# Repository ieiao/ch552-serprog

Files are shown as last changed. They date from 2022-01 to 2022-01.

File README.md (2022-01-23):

# ch552-serprog

# 简介

使用ch552设计的兼容[flashrom](https://flashrom.org) serprog协议的SPI nor flash烧录器，支持3.3V和1.8V电压。

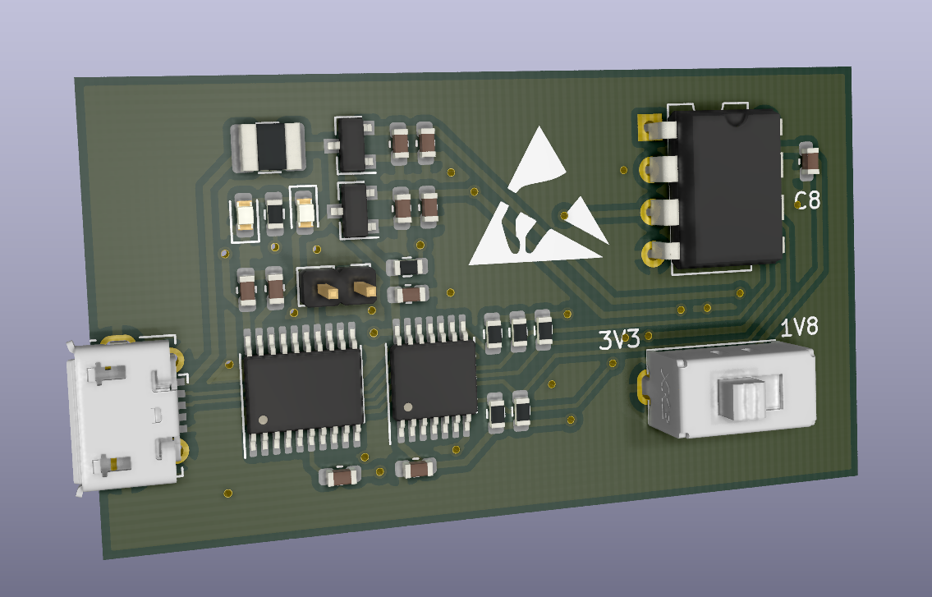
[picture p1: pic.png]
效果图


# 固件

本仓库仅包含原理图及PCB文件，程序在[这个仓库](https://github.com/ieiao/ch554_sdcc)的`serprog`分支`examples/serprog`目录下。

# 使用方法

```shell
$ # 读flash
$ flashrom -p serprog:dev=/dev/ttyACM0:4000000 -r /tmp/read.bin
$ # 擦除flash
$ flashrom -p serprog:dev=/dev/ttyACM0:4000000 -E
$ # 写flash
$ flashrom -p serprog:dev=/dev/ttyACM0:4000000 -w /tmp/read.bin
```

受ch552性能以及程序实现影响，flash读写速度未能达到上限，以下是使用SST25VF032B 32Mbit(4Mbyte) flash测出的读写平均耗时

| 操作 | 耗时 |
| :--: | :--: |
| 全片读 | 10s |
| 全片擦除 | 30s |
| 全片读+写+校验 | 32s |

# 备注

* 原理图中的led灯需要二选一焊接，不可全部焊接
* 如果使用TXS0104，flash测上拉电阻可以不焊接

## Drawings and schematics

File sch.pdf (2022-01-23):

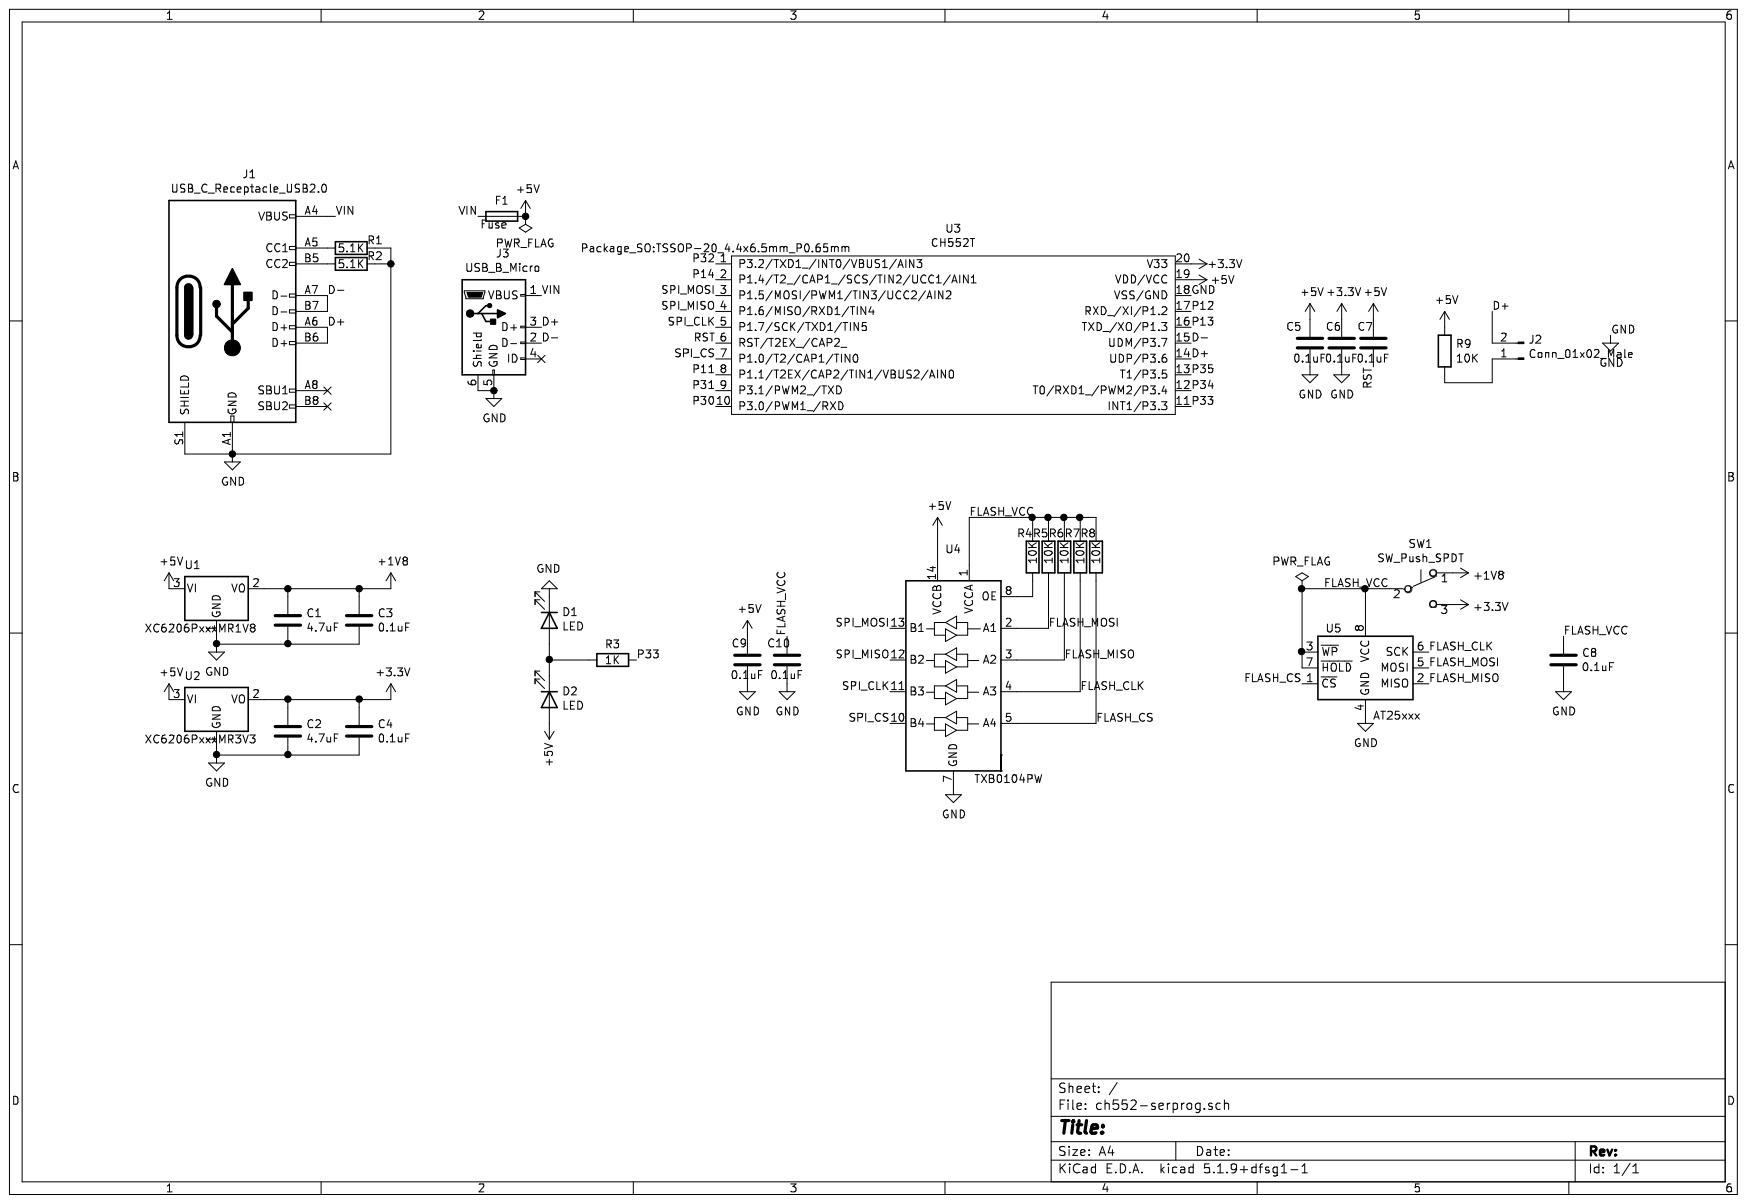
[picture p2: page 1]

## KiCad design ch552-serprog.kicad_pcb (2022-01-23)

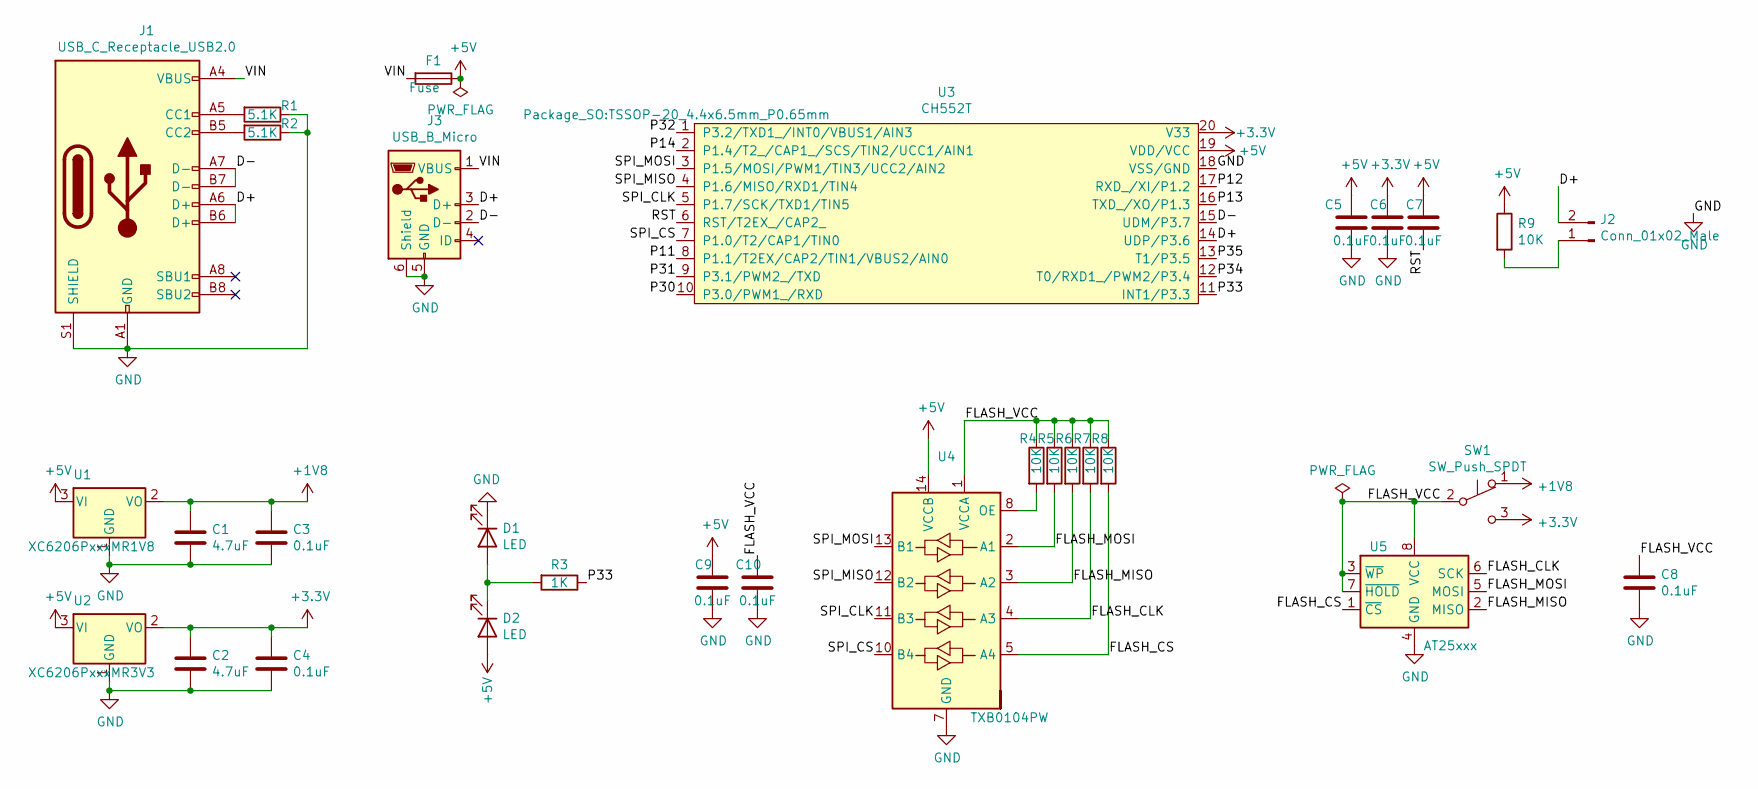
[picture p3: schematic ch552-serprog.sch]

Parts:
C1, C2: 4.7uF; C_0603_1608Metric
C3, C4, C5, C6, C7, C8, C9, C10: 0.1uF; C_0603_1608Metric
D1, D2: LED; LED_0603_1608Metric
F1: Fuse; Fuse_1210_3225Metric
J1: USB_C_Receptacle_USB2.0; USB_C_Receptacle_Palconn_UTC16-G
J2: Conn_01x02_Male; PinHeader_1x02_P2.00mm_Vertical
J3: USB_B_Micro; USB_Micro-B_Molex-105017-0001
R1, R2: 5.1K; R_0603_1608Metric
R3: 1K; R_0603_1608Metric
R4, R5, R6, R7, R8, R9: 10K; R_0603_1608Metric
SW1: SW_Push_SPDT; SW-DIP-3
U1: XC6206PxxxMR1V8; SOT-23
U2: XC6206PxxxMR3V3; SOT-23
U3: CH552T; TSSOP-20_4.4x6.5mm_P0.65mm
U4: TXB0104PW; TSSOP-14_4.4x5mm_P0.65mm
U5: AT25xxx; DIP-8_W7.62mm

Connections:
+1V8: C1.1, C3.1, SW1.1 (A), U1.2 (VO)
+3V3: C2.1, C4.1, C6.2, SW1.3 (C), U2.2 (VO), U3.20 (V33)
+5V: C5.2, C7.2, C9.2, D2.2 (A), F1.1, R9.1, U1.3 (VI), U2.3 (VI), U3.19 (VDD/VCC), U4.14 (VCCB)
/D+: J1.A6 (D+), J1.B6 (D+), J2.2, J3.3 (D+), U3.14 (UDP/P3.6)
/D-: J1.A7 (D-), J1.B7 (D-), J3.2 (D-), U3.15 (UDM/P3.7)
/FLASH_CLK: R7.2, U4.4 (A3), U5.6 (SCK)
/FLASH_CS: R8.2, U4.5 (A4), U5.1 (~CS)
/FLASH_MISO: R6.2, U4.3 (A2), U5.2 (MISO)
/FLASH_MOSI: R5.2, U4.2 (A1), U5.5 (MOSI)
/FLASH_VCC: C8.1, C10.2, R4.1, R5.1, R6.1, R7.1, R8.1, SW1.2 (B), U4.1 (VCCA), U5.3 (~WP), U5.7 (~HOLD), U5.8 (VCC)
/P11: U3.8 (P1.1/T2EX/CAP2/TIN1/VBUS2/AIN0)
/P12: U3.17 (RXD_/XI/P1.2)
/P13: U3.16 (TXD_/XO/P1.3)
/P14: U3.2 (P1.4/T2_/CAP1_/SCS/TIN2/UCC1/AIN1)
/P30: U3.10 (P3.0/PWM1_/RXD)
/P31: U3.9 (P3.1/PWM2_/TXD)
/P32: U3.1 (P3.2/TXD1_/INT0/VBUS1/AIN3)
/P33: R3.1, U3.11 (INT1/P3.3)
/P34: U3.12 (T0/RXD1_/PWM2/P3.4)
/P35: U3.13 (T1/P3.5)
/RST: C7.1, U3.6 (RST/T2EX_/CAP2_)
/SPI_CLK: U3.5 (P1.7/SCK/TXD1/TIN5), U4.11 (B3)
/SPI_CS: U3.7 (P1.0/T2/CAP1/TIN0), U4.10 (B4)
/SPI_MISO: U3.4 (P1.6/MISO/RXD1/TIN4), U4.12 (B2)
/SPI_MOSI: U3.3 (P1.5/MOSI/PWM1/TIN3/UCC2/AIN2), U4.13 (B1)
/VIN: F1.2, J1.A4 (VBUS), J1.A9 (VBUS), J1.B4 (VBUS), J1.B9 (VBUS), J3.1 (VBUS)
GND: C1.2, C2.2, C3.2, C4.2, C5.1, C6.1, C8.2, C9.1, C10.1, D1.1 (K), J1.A1 (GND), J1.A12 (GND), J1.B1 (GND), J1.B12 (GND), J1.S1 (SHIELD), J3.5 (GND), J3.6 (Shield), R1.1, R2.1, U1.1 (GND), U2.1 (GND), U3.18 (VSS/GND), U4.7 (GND), U5.4 (GND)
unnamed: D1.2 (A), D2.1 (K), R3.2
unnamed: J1.A5 (CC1), R1.2
unnamed: J1.B5 (CC2), R2.2
unnamed: J2.1, R9.2
unnamed: R4.2, U4.8 (OE)

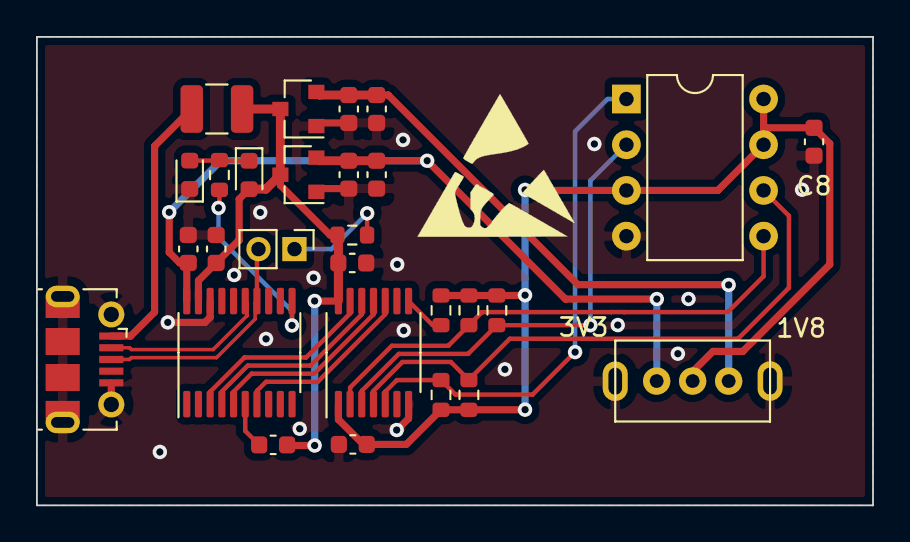
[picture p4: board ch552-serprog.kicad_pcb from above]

Board: 2 copper layers, 46.4 x 26.0 mm, 28 parts (0 on the bottom side), 21 nets.

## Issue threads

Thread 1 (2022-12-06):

Some suggestions

swiftgeek, 2022-12-06:
Thanks for writing serprog support for **CH552**

Since you are the author of serprog example I would suggest adding your name there
https://github.com/ieiao/ch554_sdcc/blob/serprog/examples/serprog/main.c#L3
Don't give credit to WCH for your own hard work 😉

[Description](https://github.com/ieiao/ch554_sdcc/blob/serprog/examples/serprog/main.c#L6) could be probably updated to reflect current state, like this:
```
* Description        : CH552 serprog implementation for use with flashrom
```

Additionally since the license of Blinkinlabs/ch554_sdcc repo is unclear, I would suggests adding in [README.md](https://github.com/ieiao/ch554_sdcc/blob/serprog/README.md) in your fork (in serprog branch)
`modifications made in this continuation project are, unless otherwise specified, licensed under Zero-Clause BSD` or maybe `3-Clause BSD`

So in case if upstream clears up their license, it would clear up for this project as well

ieiao, 2022-12-08:
Thank you for your suggestion. I will make changes later.

ieiao, 2022-12-12:
Changes already pushed.

Closed 2022-12-12.
